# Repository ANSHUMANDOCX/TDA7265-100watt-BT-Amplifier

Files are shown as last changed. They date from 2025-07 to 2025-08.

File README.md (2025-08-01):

# TDA7265 100 watt DUAL IC BT Amplifier 

This is a BT amp which has a max ouput of 100watt (50+50) and BT input for audio

# Parts
- TDA7265 IC x2
- MH-M18
- 12-0-12 Transformer

# Plan
I always wanted to make a powerful enough speakers to use with my Sony speaker. Now i have found a appropriate ic which can be tweaked to to get a max output of 50 watt in each channel hence 100watt total TDP.

I have use a MH-M18 BT module which is both cheap and provides lossless audio

i had made a TDA7269A amp which was a 14+14 watt Amp so this is a massive upgrade to it.





# BOM
| S.No | Description | Quantity | Total Price | Supplier |LINK|
|---|---|---|---|---|---|
| 1 | Capacitors | | $3.64 | LCSC |https://lcsc.com/product-detail/Aluminum-Electrolytic-Capacitors-Leaded_AISHI-ERR1VM102G20OT_C398835.html  https://lcsc.com/product-detail/image/50YXF1MEFC5X11_C2927584.html  https://lcsc.com/product-detail/Aluminum-Electrolytic-Capacitors-Leaded_Rubycon-50YXF1MEFC5X11_C2927584.html  https://lcsc.com/product-detail/Aluminum-Electrolytic-Capacitors-Leaded_Rubycon-50YXF10MEFC5X11_C88726.htmldc  https://lcsc.com/product-detail/Film-Capacitors_KYET-PE104J2A0501_C390170.html  https://lcsc.com/product-detail/Film-Capacitors_WEIDY-W242A562JD2TAAA4JA_C7502419.html|
| 2 | Resistor  | 5 | $3.03 | LCSC |https://lcsc.com/product-detail/Through-Hole-Resistors_VO-MF1-4W-36K-1-ST52_C2848587.html  https://lcsc.com/product-detail/Through-Hole-Resistors_YAGEO-MFR-25FBF52-560R_C1369978.html  https://lcsc.com/product-detail/Through-Hole-Resistors_CCO-Chian-Chia-Elec-CF1-4W-4-7-5-T_C119999.html  https://lcsc.com/product-detail/Through-Hole-Resistors_Huaxing-Mechanical-Elec-MF1-4W-1K-1-T52_C713997.html  https://lcsc.com/product-detail/Through-Hole-Resistors_VO-MF1-4W-10K-1-ST52_C2903232.html|
| 3 | Diode | 5 | $0.81 | LCSC |https://lcsc.com/product-detail/Diodes-General-Purpose_LGE-6A4_C5369359.html|
| 4 | Regulator ICs | 5 | $2.77 | LCSC |https://lcsc.com/product-detail/Voltage-Regulators-Linear-Low-Drop-Out-LDO-Regulators_ST-L7912CV-DG_C3797.html  https://lcsc.com/product-detail/Voltage-Regulators-Linear-Low-Drop-Out-LDO-Regulators_ST-L7812CV-DG_C2914.html  https://lcsc.com/product-detail/Voltage-Regulators-Linear-Low-Drop-Out-LDO-Regulators_ST-L7805CV-DG_C3795.html|
| 5 |TDA7265 | 2 | $3 | LCSC |https://lcsc.com/product-detail/E-ink-Display_SEEKINK-E037A49_C41416467.html?s_z=n_C41416467|
| 6 |Terminal Blocks | — | $2.32 | LCSC |https://lcsc.com/product-detail/Screw-Terminal-Blocks_JILN-JL500-50802G01_C709041.html  https://lcsc.com/product-detail/Screw-Terminal-Blocks_Ningbo-Kangnex-Elec-WJ500V-5-08-3P_C72334.html|
||TRANSFORMER+BT MODLUE+WIRE||$18 |Maker Bazaar|https://makerbazar.in/products/multi-coloured-ribbon-cable-wire?variant=40914910281879  https://makerbazar.in/products/wireless-bluetooth-audio-receiver-module?variant=46233436946672  https://makerbazar.in/products/24volt-dc-switch-mode-power-supply-smps-rectangular-metal-casing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 |
|||SHIPPING LCSC|3.75|LCSC||
|||PCB+ Shipping|12|JLCPCB||
|||**TOTAL**|48.42||

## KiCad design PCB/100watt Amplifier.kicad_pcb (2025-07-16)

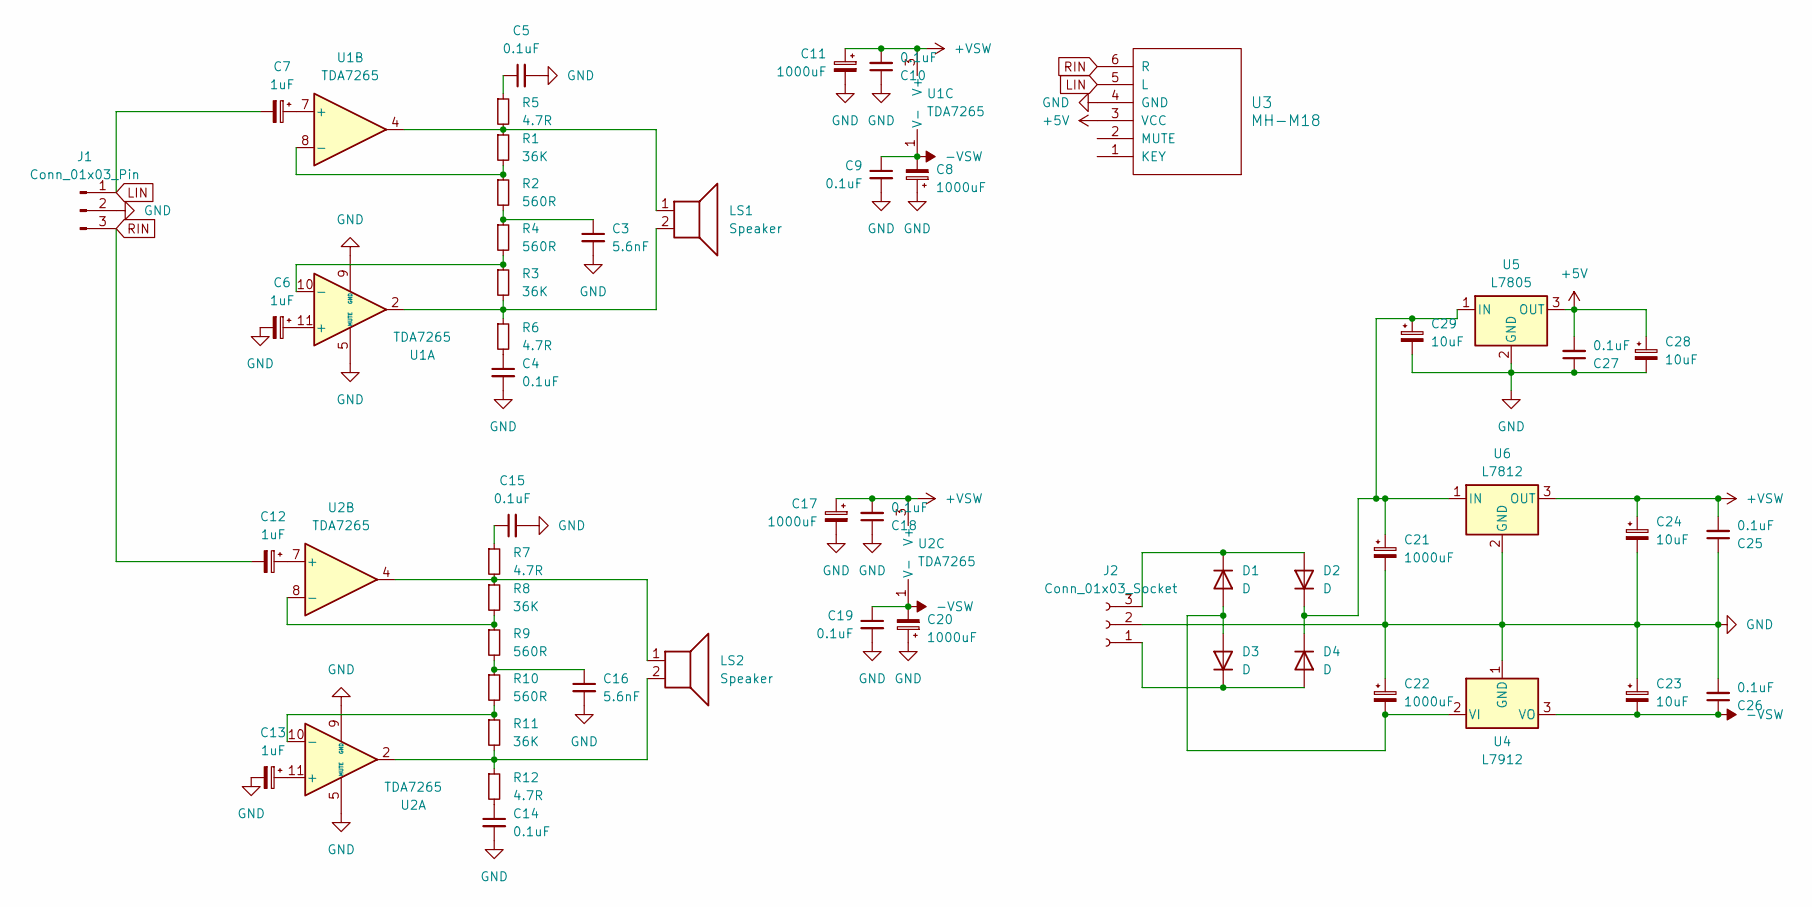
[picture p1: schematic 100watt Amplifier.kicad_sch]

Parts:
C3, C16: 5.6nF; C_Rect_L7.2mm_W2.5mm_P5.00mm_FKS2_FKP2_MKS2_MKP2
C4, C5, C9, C10, C14, C15, C18, C19, C25, C26, C27: 0.1uF; C_Rect_L7.2mm_W2.5mm_P5.00mm_FKS2_FKP2_MKS2_MKP2
C6, C7, C12, C13: 1uF; CP_Radial_D5.0mm_P2.00mm
C8, C11, C17, C20, C21, C22: 1000uF; CP_Radial_D10.0mm_P5.00mm
C23, C24, C28, C29: 10uF; CP_Radial_D5.0mm_P2.00mm
D1, D2, D3, D4: D; D_P600_R-6_P20.00mm_Horizontal
J1: Conn_01x03_Pin; PJ-3200
J2: Conn_01x03_Socket; TerminalBlock_bornier-3_P5.08mm
LS1, LS2: Speaker; TerminalBlock_bornier-2_P5.08mm
R1, R3, R8, R11: 36K; R_Axial_DIN0207_L6.3mm_D2.5mm_P10.16mm_Horizontal
R2, R4, R9, R10: 560R; R_Axial_DIN0207_L6.3mm_D2.5mm_P10.16mm_Horizontal
R5, R6, R7, R12: 4.7R; R_Axial_DIN0207_L6.3mm_D2.5mm_P10.16mm_Horizontal
U1, U2: TDA7265; TO-220-11_P3.4x5.08mm_StaggerOdd_Lead4.85mm_Vertical
U3: MH-M18
U4: L7912; TO-220-3_Vertical
U5: L7805; TO-220-3_Vertical
U6: L7812; TO-220-3_Vertical

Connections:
+5V: C27.2, C28.1, U3.3 (VCC), U5.3 (OUT)
+VSW: C10.2, C11.1, C17.1, C18.2, C24.1, C25.2, U1.3 (V+), U2.3 (V+), U6.3 (OUT)
-VSW: C8.2, C9.1, C19.1, C20.2, C23.2, C26.1, U1.1 (V-), U1.6 (V-), U2.1 (V-), U2.6 (V-), U4.3 (VO)
GND: C3.2, C4.2, C5.2, C6.2, C8.1, C9.2, C10.1, C11.2, C13.2, C14.2, C15.2, C16.2, C17.2, C18.1, C19.2, C20.1, C21.2, C22.1, C23.1, C24.2, C25.1, C26.2, C27.1, C28.2, C29.2, J1.2, J2.2, U1.5 (MUTE), U1.9 (GND), U2.5 (MUTE), U2.9 (GND), U3.4 (GND), U4.1 (GND), U5.2 (GND), U6.2 (GND)
LIN: C7.2, J1.1, U3.5 (L)
unnamed: C3.1, R2.2, R4.1
unnamed: C4.1, R6.2
unnamed: C5.1, R5.1
unnamed: C14.1, R12.2
unnamed: C15.1, R7.1
unnamed: C16.1, R9.2, R10.1
unnamed: C22.2, D1.2 (A), D3.2 (A), U4.2 (VI)
unnamed: D1.1 (K), D2.2 (A), J2.3
unnamed: C21.1, C29.1, D2.1 (K), D4.1 (K), U5.1 (IN), U6.1 (IN)
unnamed: D3.1 (K), D4.2 (A), J2.1
unnamed: LS1.1, R1.1, R5.2, U1.4
unnamed: LS1.2, R3.2, R6.1, U1.2
unnamed: LS2.1, R7.2, R8.1, U2.4
unnamed: LS2.2, R11.2, R12.1, U2.2
unnamed: C6.1, U1.11 (+)
unnamed: R3.1, R4.2, U1.10 (-)
unnamed: C7.1, U1.7 (+)
unnamed: R1.2, R2.1, U1.8 (-)
unnamed: C13.1, U2.11 (+)
unnamed: R10.2, R11.1, U2.10 (-)
unnamed: C12.1, U2.7 (+)
unnamed: R8.2, R9.1, U2.8 (-)
RIN: C12.2, J1.3, U3.6 (R)

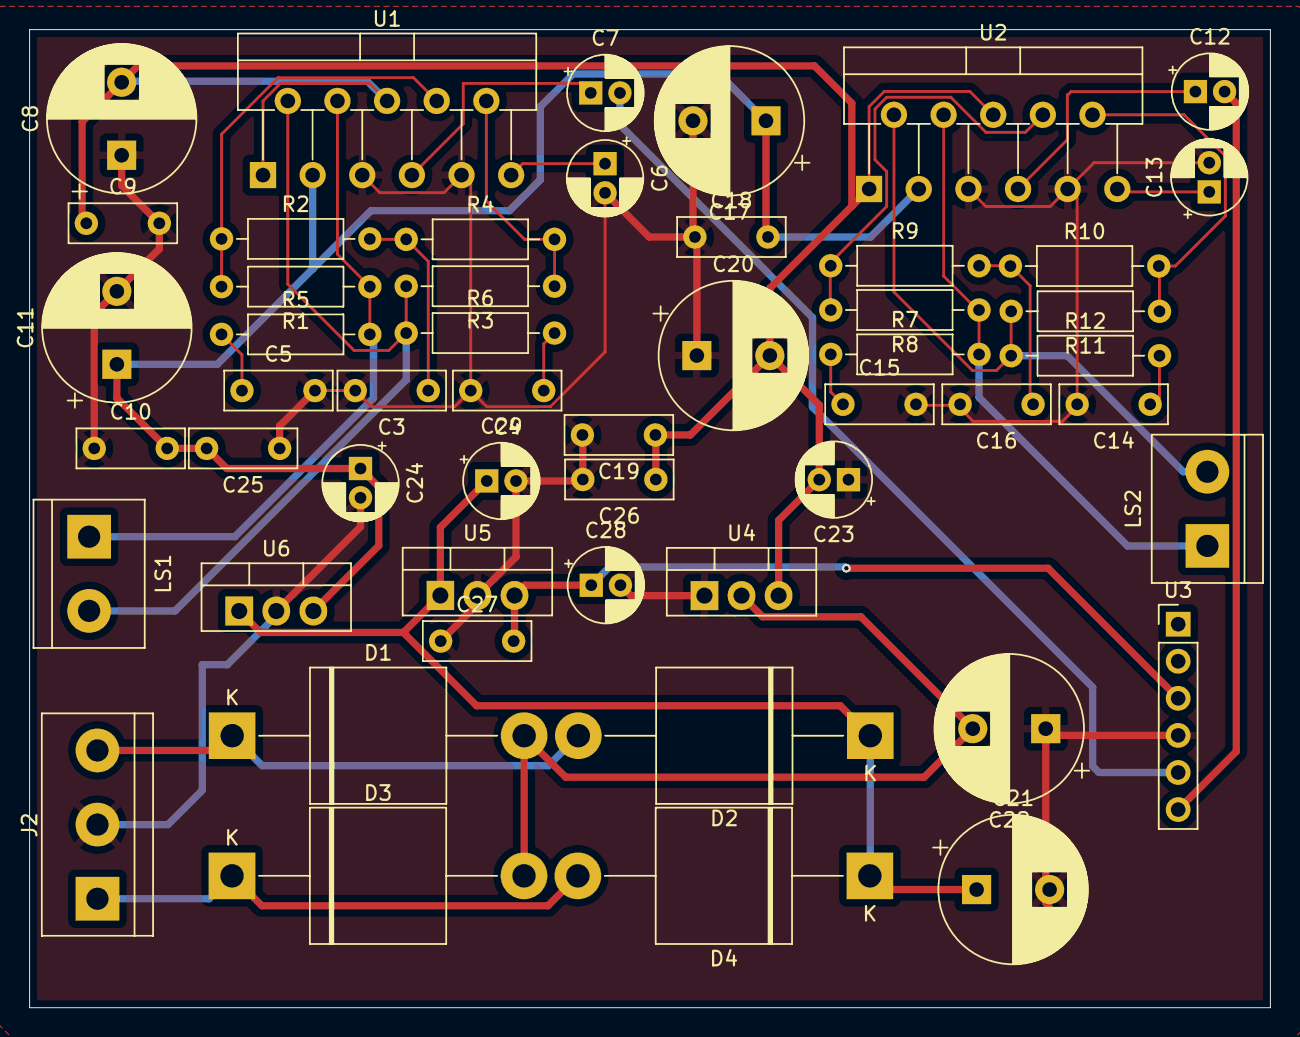
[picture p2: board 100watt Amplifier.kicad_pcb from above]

Board: 2 copper layers, 85.0 x 67.0 mm, 52 parts (0 on the bottom side), 28 nets.

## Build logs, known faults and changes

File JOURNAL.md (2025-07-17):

---
title: "Dual TDA72665 BT AMP"
author: "Anshuman Tripathy"
description: "Dual tda7265 and mh-m10 Based 100watt BT amplifier"
created_at: "2025-07-11"
total_time_spent: 9hr
---

 ## **DAY 1 :11th july 2025 Read the Datasheets**

 Started out by reading the datasheet and figuring out how to get 50watt output in one speaker. Also researched about the power supply that i would need to run this i am likely going to need a Transformer of a SMPS will be adding the Compatibilities of both in the circuit

 Time spent-2 hr

## **DAY 2 :13th July 2025 Completed the Schematics and Componenet assignment **

made dual speaker output using 2 of 7265 Ic for 50 watt output each also added a split supply to convert 12-0-12 to +12 and -12v. 


Time spent-2hr

## **DAY 3 :16th July 2025 Assigned the Components and PCB**
Assigned the components and complted the PCB checked and shortlisted all the Parts i will be requiring.
Since this is a audio based circuit so i had to keeep in mind the noise that might be there due to the signal interferenece.


Time spent - 5hrs
